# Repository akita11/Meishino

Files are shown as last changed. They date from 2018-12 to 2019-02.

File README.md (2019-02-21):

# Meishino (ver 1.2)

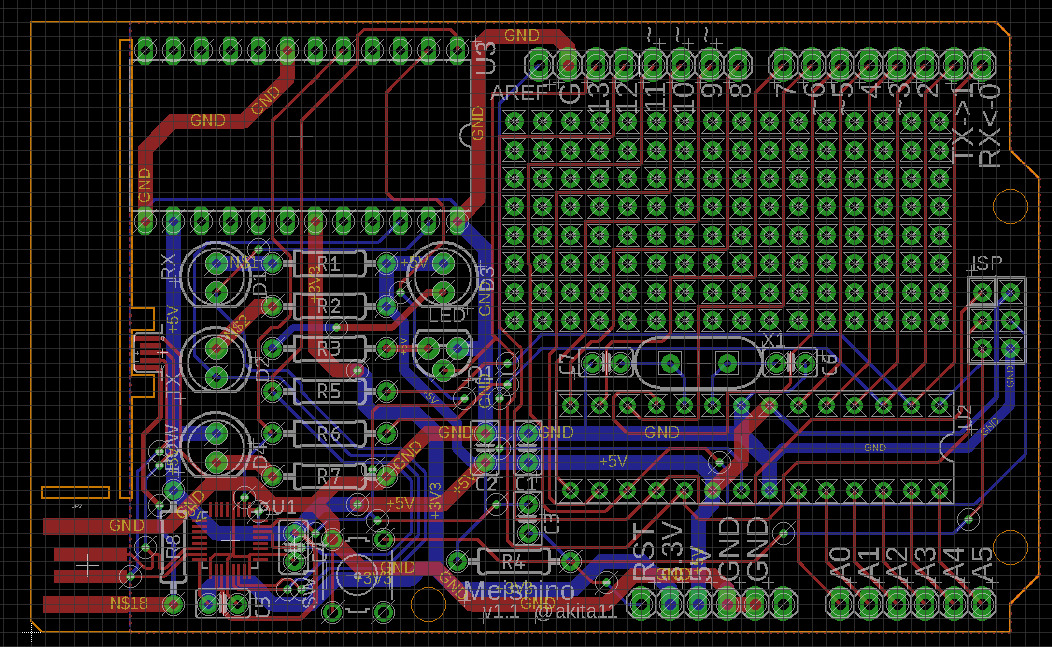
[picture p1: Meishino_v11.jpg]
基板外形


つくった基板を名刺代わりに。
裏面の空いているところ（以下の赤丸で示したエリア）に、自分の名前などをシルクで入れれば、オリジナル基板のできあがり。
あとは製造発注して、名刺代わりに配りましょう。
Arduino UNO互換機と使えます。

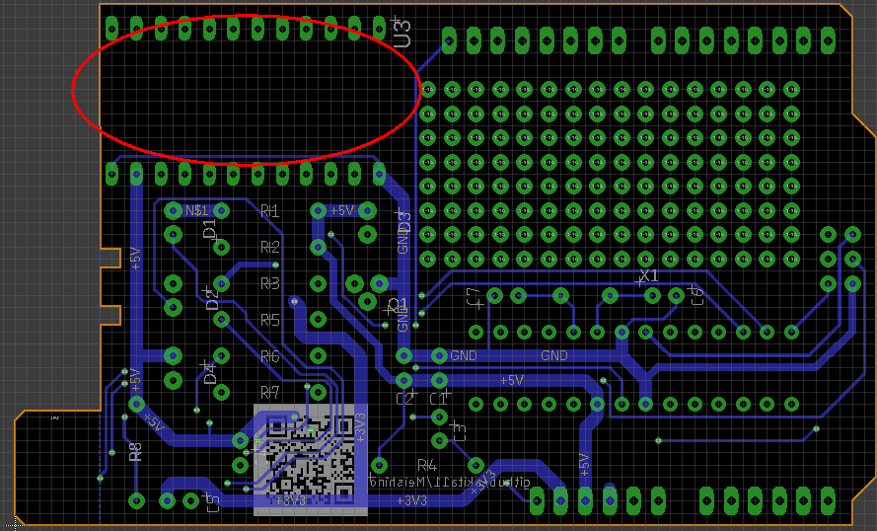
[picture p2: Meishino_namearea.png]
名前記載エリア


基板の製造と部品の調達・実装によって、以下の3パターンのいずれかを製作できます。
1. USB-シリアル変換モジュール使用(挿入実装のはんだ付けだけで作れます）
2. 基板のmicroUSBケーブルで使う(1個だけ表面実装部品(QFNパッケージ)のはんだ付けが必要です)
3. 基板の基板を直接USBコネクタに挿して使う(1個だけ表面実装部品(QFNパッケージ)のはんだ付けが必要です)

# 製造仕様

ガーバーデータ（Meishino_v12_gerber.zip）を使います。

挿入実装で使う場合(上記1.)は、板厚はいくつでもかまいませんが、名刺として使えるように薄くする(0.6mmなど)のがおすすめです。

表面実装ICを使う場合は、製造発注時には、板厚を以下のいずれかを選びます。
- 板厚を2.0mmとすると、USBコネクタへ直接挿して使うことができます。(上記の2.)
- 板厚を0.6mmとすると、microUSBケーブルを使うことができます。（以下のUSBコネクタ直挿しを使うためには、コネクタ部分に1.4mm程度の厚紙などをはさみます）（上記の2.または3.）
- 板厚を自由（標準は1.6mm）とする（上記の1.）

# 部品の調達と実装

以下のいずれかを選んで、部品表(Meishino_v12_bom.csv)の部品を[秋月電子](http://akizukidenshi.com/)から購入し、部品をはんだ付けします。
- 表面実装のIC(QFNパッケージ)をはんだ付けできる方：U3以外の部品を使用します
- 表面実装のIC(QFNパッケージ)をはんだ付けできない：U1,C4,C5,R8以外の部品を使用します

# Author

Junichi Akita (@akita11, akita@ifdl.jp)

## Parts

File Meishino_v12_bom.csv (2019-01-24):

Part | Description | Qty | Price at Akizuki | Akizuki's PN | memo
C1,C2,C3 | Ceramic Capacitor, 0.1uF | 3 | 10 | P-04065 | 10個入り100円
C6,C7 | Ceramic Capacitor, 22pF | 2 | 5 | P-11137
CN1,CN2 | 1x6 pin socket | 2 | 20 | C-03784
CN3,CN4 | 1x8 pin socket | 2 | 30 | C-03785
CN5 | 2x3 pin header | 1 | 15 | C-13635 | 2x5ピンを切って使う
D1,D4 | LED, 5mm, Green | 2 | 10 | I-12606
D2 | LED, 5mm, Red | 1 | 10 | I-12605
D3 | LED, 5mm, Yellow | 1 | 10 | I-12607
Q1 | 2N7000 | 1 | 20 | I-09723
R1,R2,R3,R4,R5,R6,R7 | 1k 1/4W | 7 | 1 | R-25102 | 100本入り100円
SW1 | TactSW(黒) | 1 | 10 | P-03647 | 色はお好みで
U2 | ATmega328P | 1 | 230 | I-03142 | BL書き込み済み：I-12774 (320円)
X1 | Xtal, 16MHz | 1 | 30 | P-08671
U3 | AE_FT232 | 1 | 800 | K-06693 | 完成品：K-01977(950円)
U1 | FT232RQ | 1 | 380 | I-04365 | 2個入り760円
C4 | Ceramic Capacitor, 0.1uF | 1 | 10 | P-04065
C5 | Ceramic Capacitor, 1uF | 1 | 20 | P-08150
R8 | PolySW, 0.5A | 1 | 30 | P-12628

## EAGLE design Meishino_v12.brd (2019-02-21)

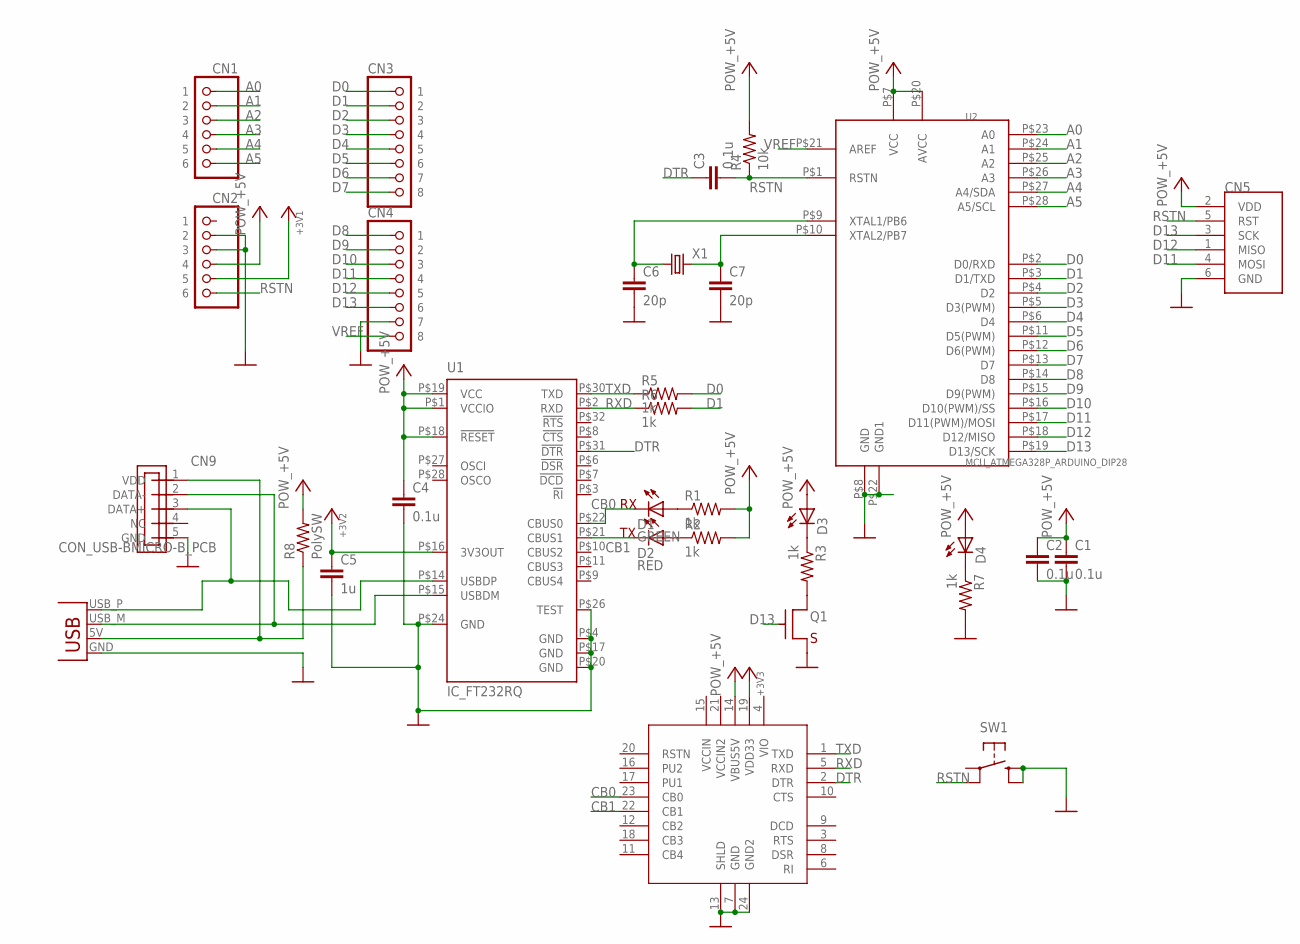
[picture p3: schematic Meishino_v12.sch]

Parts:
C1, C2, C3, C4: 0.1u; CAP_TH_5MM_L
C5: 1u; CAP_TH_5MM_L
C6, C7: 20p; CAP_TH_5MM_L
CN1, CN2: CON_PINHD-1X6; 1X06
CN3, CN4: CON_PINHD-1X8; 1X08
CN5: CON_AVRISPTH; 2X03R
CN9: CON_USB-BMICRO-B_PCB; USB-MICRO-PCB
D1: GREEN; SPARKFUN_LED5MM
D2: RED; SPARKFUN_LED5MM
D3, D4: LED5MM; SPARKFUN_LED5MM
JP2: CON_USBPCB; USB-A-PCB
Q1: TR_NMOS_2N7000; TO-92
R1, R2, R3, R5, R6, R7: 1k; R_TH_10MM_L
R4: 10k; R_TH_10MM_L
R8: PolySW; R_TH_10MM_L
SW1: SW_TACTTH; SW_B3F-10XX
U1: IC_FT232RQ; QFN32
U2: MCU_ATMEGA328P_ARDUINO_DIP28; DIP-28P(300MIL)
U3: MOD_AE_FT232_DIP24; DIP24_600MIL
X1: XTAL2HC49US; HC49US

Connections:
+3V3: C5.1, CN2.5, U1.P$16 (3V3OUT), U3.19 (VDD33)
+5V: C1.1, C2.1, C4.1, CN2.4, CN5.2 (VDD), D3.A, D4.A, R1.2, R2.2, R4.2, R8.2, U1.P$1 (VCCIO), U1.P$18 (!RESET), U1.P$19 (VCC), U2.P$7 (VCC), U2.P$20 (AVCC), U3.14 (VBUS5V)
A0: CN1.1, U2.P$23 (A0)
A1: CN1.2, U2.P$24 (A1)
A2: CN1.3, U2.P$25 (A2)
A3: CN1.4, U2.P$26 (A3)
A4: CN1.5, U2.P$27 (A4/SDA)
A5: CN1.6, U2.P$28 (A5/SCL)
CB0: D1.K (C), U1.P$22 (CBUS0), U3.23 (CB0)
CB1: D2.K (C), U1.P$21 (CBUS1), U3.22 (CB1)
D0: CN3.1, R5.2, U2.P$2 (D0/RXD)
D1: CN3.2, R6.2, U2.P$3 (D1/TXD)
D2: CN3.3, U2.P$4 (D2)
D3: CN3.4, U2.P$5 (D3(PWM))
D4: CN3.5, U2.P$6 (D4)
D5: CN3.6, U2.P$11 (D5(PWM))
D6: CN3.7, U2.P$12 (D6(PWM))
D7: CN3.8, U2.P$13 (D7)
D8: CN4.1, U2.P$14 (D8)
D9: CN4.2, U2.P$15 (D9(PWM))
D10: CN4.3, U2.P$16 (D10(PWM)/SS)
D11: CN4.4, CN5.4 (MOSI), U2.P$17 (D11(PWM)/MOSI)
D12: CN4.5, CN5.1 (MISO), U2.P$18 (D12/MISO)
D13: CN4.6, CN5.3 (SCK), Q1.2 (G), U2.P$19 (D13/SCK)
DTR: C3.1, U1.P$31 (!DTR), U3.2 (DTR)
GND: C1.2, C2.2, C4.2, C5.2, C6.2, C7.2, CN2.2, CN2.3, CN4.7, CN5.6 (GND), CN9.5 (GND), JP2.GND, Q1.1 (S), R7.2, SW1.1 (S), SW1.2 (S1), U1.P$4 (GND), U1.P$17 (GND), U1.P$20 (GND), U1.P$24 (GND), U1.P$26 (TEST), U2.P$8 (GND), U2.P$22 (GND1), U3.7 (GND), U3.13 (SHLD), U3.24 (GND2)
unnamed: D1.A, R1.1
unnamed: D2.A, R2.1
unnamed: D3.K (C), R3.1
unnamed: CN9.3 (DATA+), JP2.USB_P (D+), U1.P$14 (USBDP)
unnamed: CN9.2 (DATA-), JP2.USB_M (D-), U1.P$15 (USBDM)
unnamed: D4.K (C), R7.1
unnamed: C6.1, U2.P$9 (XTAL1/PB6), X1.1
unnamed: C7.1, U2.P$10 (XTAL2/PB7), X1.2
unnamed: CN9.1 (VDD), JP2.5V (VBUS), R8.1
unnamed: Q1.3 (D), R3.2
RSTN: C3.2, CN2.6, CN5.5 (RST), R4.1, SW1.4 (P1), U2.P$1 (RSTN)
RXD: R6.1, U1.P$2 (RXD), U3.5 (RXD)
TXD: R5.1, U1.P$30 (TXD), U3.1 (TXD)
VREF: CN4.8, U2.P$21 (AREF)

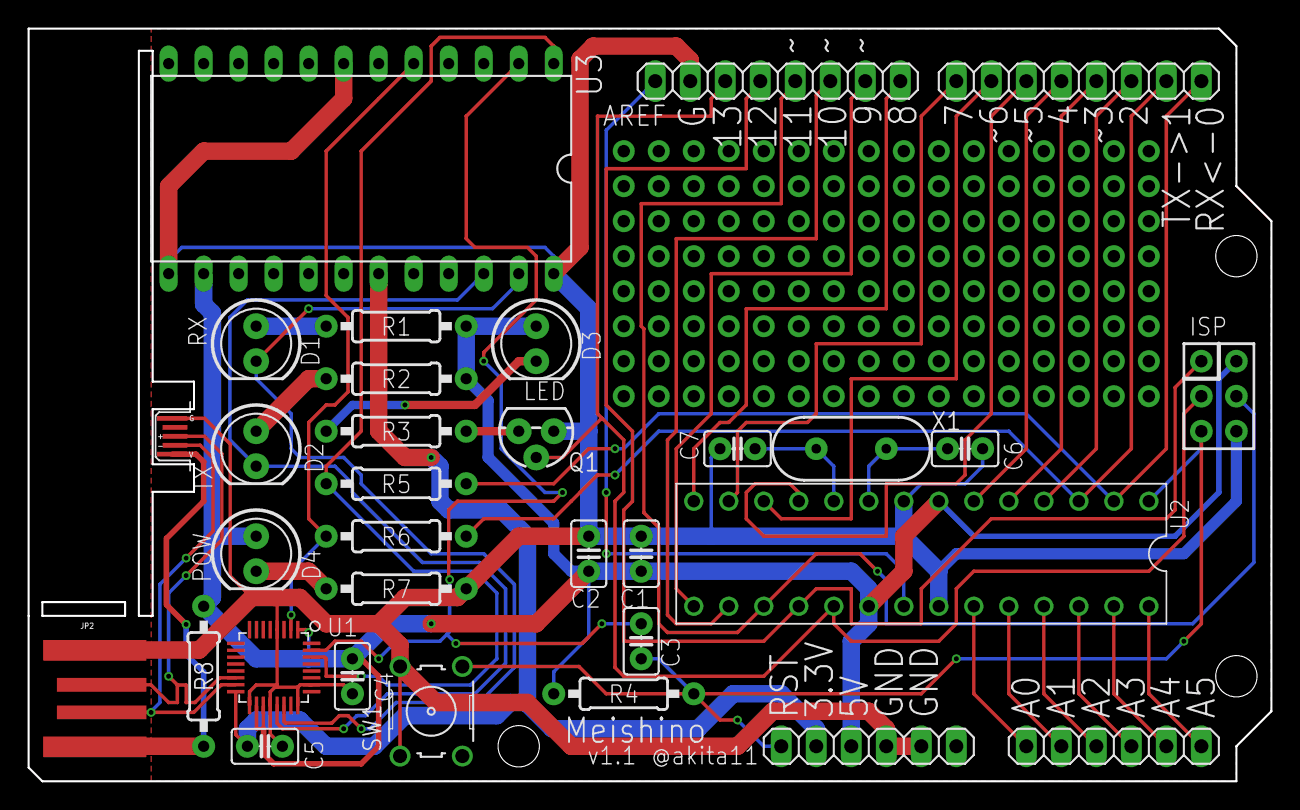
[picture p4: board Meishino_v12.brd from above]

Board: 2 copper layers, 90.2 x 54.6 mm, 32 parts (0 on the bottom side), 40 nets.

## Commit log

2018-12-30 1st commit
    [Meishino_v10.brd, Meishino_v10.sch, Meishino_v10_bom.csv]
2018-12-30 名前の記載エリア図を追加
2018-12-30 基板参照図の追加
2019-01-24 リセットとネジ穴を追加、シルクの調整。
    [Meishino_v11.brd, Meishino_v11.sch, Meishino_v11_bom.csv]
2019-01-28 基板uUSBコネクタの形状を修正
    [Meishino_v11.brd]
2019-02-21 ユニバーサルエリアのViaにStopがなかったのを修正(ver1.2)
    [Meishino_v12.brd, Meishino_v12.sch, Meishino_v12_bom.csv]
